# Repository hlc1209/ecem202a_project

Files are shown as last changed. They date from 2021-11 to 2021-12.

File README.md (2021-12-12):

# ECEM202A Project
## BLE-enabled HID based on Edge Inference Accelerated Handwriting Recognition
This is repository template for UCLA ECEM202A / CSM213A projects.

Use the folders as follows:

* doc/ for website content
* software/ for code used in your project
* data/ for data data used in your project

You may add additional folders as necessary

# Website URL
https://hlc1209.github.io/ecem202a_project/

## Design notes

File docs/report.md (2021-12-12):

# Final Report
# Table of Contents
* Abstract
* [Introduction](#1-introduction)
* [Related Work](#2-related-work)
* [Technical Approach](#3-technical-approach)
* [Evaluation and Results](#4-evaluation-and-results)
* [Discussion and Conclusions](#5-discussion-and-conclusions)
* [References](#6-references)

# Abstract

In this project, we build a low-cost, small-size and low-power real-time handwritten character recognition system based on Arduino Nano 33 BLE Sense with a touch screen, which is capable of offering fluent handwriting input experience in real-time and send recognized characters to BLE-enabled terminal equipment as keyboard strokes. Inference of character recognition deep learning model is done on the Arduino Nano 33 BLE Sense to enable the compatibility to any BLE-enabled devices. We achieve a accuracy of 80.6% in fast mode with a latency of 200ms and 95.4% in slow mode. In addition, we designed the PCB and 3D printed case for the device to reduce the use of flying wires and to make the device integrated and portable.

<p align="middle">
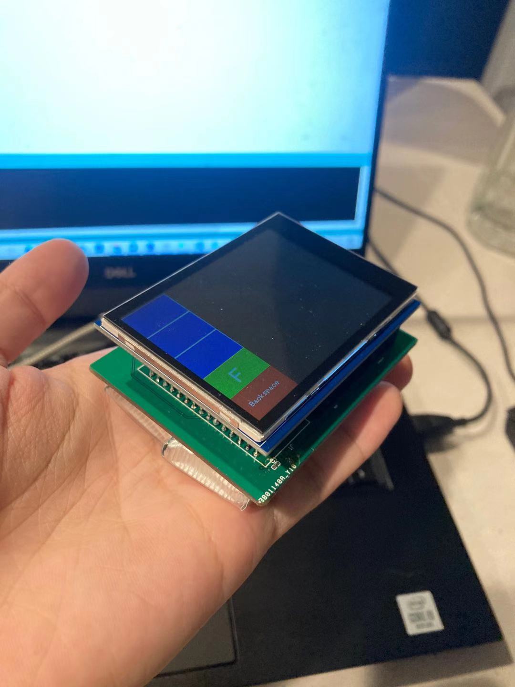
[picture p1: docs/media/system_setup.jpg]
    
</p>

# 1. Introduction

#### 1.1 Motivation & Objective
Designers have long recognized that handwriting with a pen offers more fluidity compared with typing. After the keyboard has been the dominant input device for electronics for years, stylus pen comes into play as another commonly-used input device for electronics. While stylus pen becomes increasingly popular over the years, problems remain in this type of device, which could be turned into sizable market if properly solved. 

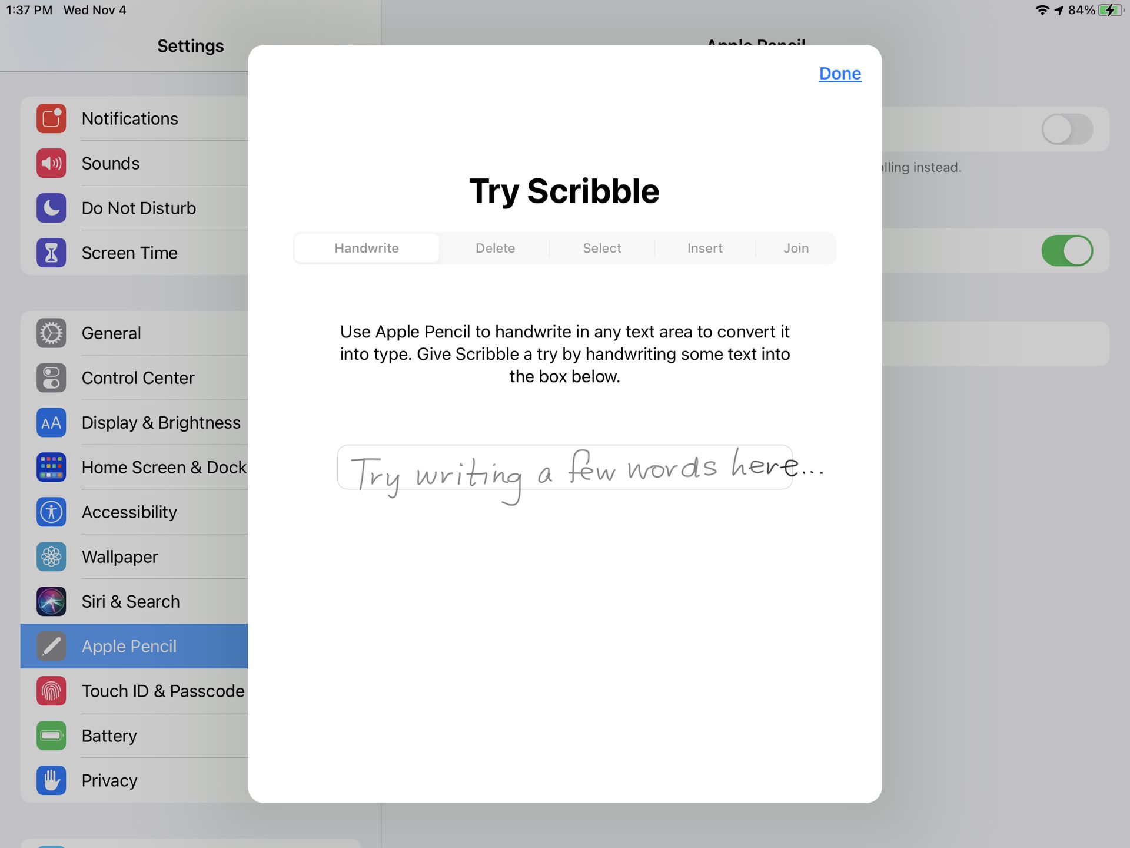
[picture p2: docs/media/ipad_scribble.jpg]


First, the cost of handwritten-enabled devices with a smooth experience is high. Currently, multiple solutions exist for scribble digitization. For example, Microsoft Surface Pro has a built-in Wacom-made digitizer layer and a pen designed for it to achieve such functionality. Apple iPad introduced the scribble feature in iOS 14 with an extremely enhanced seamless handwriting input experience, but it requires the powerful computing power of the A14 chip and a separately sold apple pencil. Other solutions like capacitive and bluetooth stylus have readily lower cost. Still, they can only work with devices with touchscreen enabled and rely on hardware-specific optimized software to deliver a good experience. It is undeniably true that the vast majority of low-end devices offer a very poor handwriting experience.

Secondly, hardware support is relatively stringent. Most of the handwritten solutions for electronics does not generalize well to different devices and mainly focus on the need of high-end electronics. Also, if handwritten characters are used as input, the recognition of handwritten characters becomes the burden on the interfaced device, placing demands on the system's software and hardware performance, increasing the system's complexity and reducing its reliability and real-time performance.

To tackle the aforementioned problems, we propose to develop a low-cost and low-power device with a capacitive touchscreen that is able to offers a fluent handwriting input experience and send commands/keyboard strokes to bluetooth low energy (BLE) enabled devices as an alternative to conventional keyboard input. Such device is essentially a new type of human interface devices (HID) and able to work universally with any BLE enabled devices with minimum change in firmware. Since the handwritten recognition is done on this embedded device, there would be little hardware constraints for the interfaced devices except BLE capability. 

#### 1.2 Novelty & Rationale

Nowadays, handwritten recognition solutions either work on specialized devices or touchscreen enabled high-end electronics, e.g., BMW iDrive infotainment system and Apple iPad. Also, the handwritten recognition algorithm of these devices typical requires the support of powerful processors. We envision a system with a small touch screen built in to collect handwritten inputs and infer the written characters on chip before sending out the commands/keyboard strokes. 

Therefore, high compatibility and fluent input experience on a low-cost, low-power compact device is the main aspect that makes our proposed device stand out from other touchscreen solutions available in the market. 

Moreover, given the flexibility of handwritten input, the device has unlimited possibilities for extended functionality. For example, performing calculations on handwritten numbers and symbols and transmitting the final results to the terminal equipment via BLE.

#### 1.3 Potential Impact

If successfully made, this device could become a new type of human interface device that is compatible to any BLE enable devices not limited to high-end electronics like laptops and tablets. For instance, it could be used to recognize and convert user's writings to keyboard strokes to replace the functionality of a keyboard upon user's desire. Similarly, it could also become an input device of speech-synthesizer for speech impaired people. 

In short, such device brings a new way of electronic interface with high performance, great compatibility and low cost. 

#### 1.4 Challenges

First of all, the experience of handwriting recognition input is critical, i.e., low latency, high accuracy and high efficiency. After we decided to use on-device deep learning inference for handwriting character recognition, it became pivotal to implement fast and accurate model inference while handling GUI drawing, user stroke input and BLE transmission on an ultra-low power device. Secondly, how to achieve fluent handwriting input on ultra-low power devices is to be overcome. We need a deep collaboration of deep learning models and GUI to achieve this. Likewise, data transmission via BLE is very important and needs to be user friendly, low latency and highly reliable. 

#### 1.5 Requirements for Success

To build such a system, the following skill sets and resources are needed.

Skill sets
* Embedded system
* Real-time operating system
* Bluetooth Low Energy (BLE)
* SPI and I2C
* Electronics
* Machine Learning and model compression

Skill sets potentially in need
* PCB design
* Mechanical Design

Hardware
* Arduino Nano 33 BLE Sense
* Adafruit 2.8" TFT Touch Shield v2 (capacitive touch)
* Breadboard

Hardware potentially in need
* Boost converter
* 3d Printer

#### 1.6 Metrics of Success: 

The success of the project will be evaluated through the following metrics. 

1. Accuracy:
   The success rate of recognizing written characters.

2. Response time:
   The time from finishing writing a character to the completion of transmission.

3. Fluentness: 
   The time to write a series of characters.

4. Power consumption:
   The power consumption of the entire system.

5. Size & Weight:
   The size and weight of the overall system.

# 2. Related Work

In 2018, Fernández et. al developed a real-time handwritten letter recognition system based on Raspberry Pi 3 using ConvNets which is able to achieve an accuracy of 93.4% and an average response time of 21.9 ms. This is the best performance of all similar systems that run the machine learning model offline considering accuracy, response, power consumption, and size. 

However, limitations remain on this system. First, the machine learning used in this system is still too large for the microcontroller. Also the model could be further compressed with proper pruning, quantization, and other model compression techniques. Second, by replacing the Raspberry Pi 3 with a low-power microcontroller (i.e., the Arduino Nano 33 BLE Sense in our case), the power consumption and size of the system can be further reduced. Finally and most importantly, this article only demonstrates the feasibility of individual character recognition using deep learning networks in embedded systems, and does not illustrate the performance of handwriting recognition in real-world applications when coupled with peripherals, such as touch screen and BLE-enabled terminals. 

In 2019, Google Research uses recurrent neural network to enable seamless handwriting input on Android devices. Unlike traditional hand-designed heuristics to cut the handwritten input into single characters, Google build an RNN model that operates on the whole input. They convert a series of handwritten inputs into a sequence of Bessel curves that are fed into the RNN to get the actual written characters.

Nevertheless, this powerful approach relies on strong chips on Android devices and even requires specially designed chips like Google Tensor with TPU cores to deliver smooth interactions, which is unacceptable in our project.

# 3. Technical Approach

## 3.1 Operation Logic
The User Interface of the device is shown in figure below. The black square area allows user to write/draw characters with fingers or stylus pen. The left panel is divided into 5 parts. The first 3 buttons on the top are the selection buttons used in slow mode. The 4th button from the top is used to switch between fast and slow mode. The red backspace button is used to delete text or clear screen without sending the keyboard stroke in slow mode. 

<p align="middle">
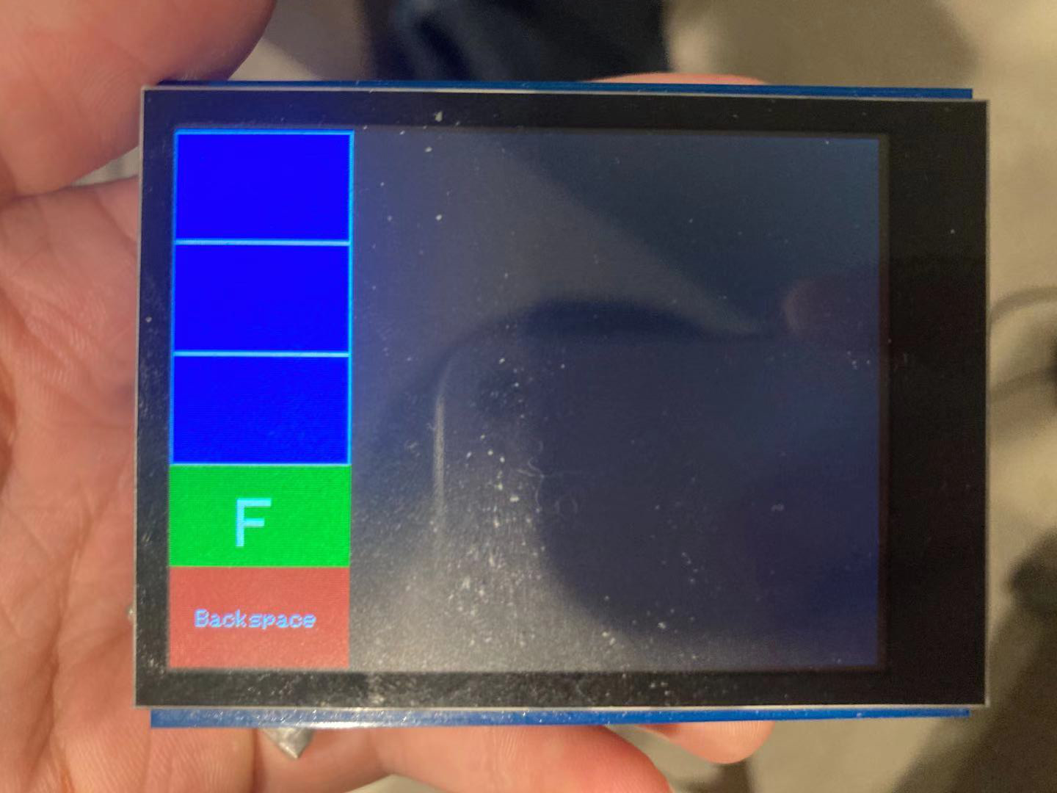
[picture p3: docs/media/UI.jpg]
    
</p>

#### Fast Mode 
In fast mode, after the user is done writing one character, the character with the highest score from inference is sent out through Bluetooth Low Energy immediately. Such setup allows maximum input speed.

#### Slow Mode
In slow mode, the written character will not be sent out instantly after the inference is done. Rather, the characters with the top 3 scores from the inference will be printed in the blue panel, allowing users to confirm and select the correct character to send out as keyboard stroke. If none of the inferred character matches user's input, the user can simply tap the 'backspace' button to clear the screen and rewrite the character. With such design, the input speed is slower in exchange for more robust inference.

<p align="middle">
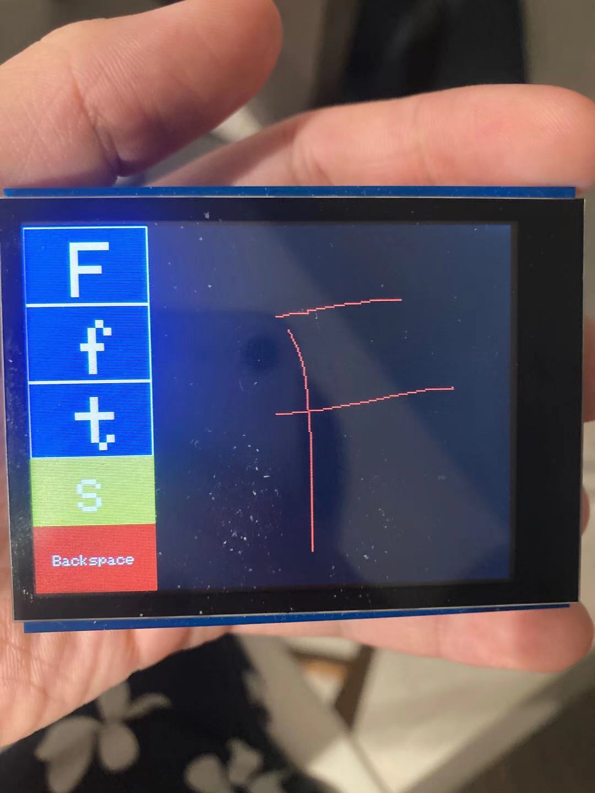
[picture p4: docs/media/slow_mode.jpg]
    
</p>

## 3.2 Bluetooth Low Energy
In contrast to Bluetooth classic, BLE is designed for significantly low power consumption, which is suitable for our application. Keyboard service is a reserved service in BLE, which eliminates the burden of writing custom service to send keyboard strokes. The inferred character will be written as BLE characteristic to BLE keyboard service to achieve the wireless keyboard functionality.

## 3.3 Image Resizing
The size of black canvas that records user's drawing is 240-by-240, which is 57.6k input parameters in total. Indeed, high-resolution image typically enables better prediction accuracy through neural network. However, considering the computing resource provided by Arduino Nano 33 BLE Sense, it is necessary to reduce the model size to deploy the model to Arduino Nano 33 BLE Sense with real-time inference. Also, pixels are represented by truth values.

For fast resizing, we use box sampling to sum the pixel values in a box and skip the rest of the values once the sum is greater than 0. During testing, we realized the recognition accuracy is affected by the thickness of strokes. Therefore, we artificially increase the stroke thickness by 3 times when performing downsizing. A comparison of writing on screen and the resized image is shown in figure below.

<p align="middle">
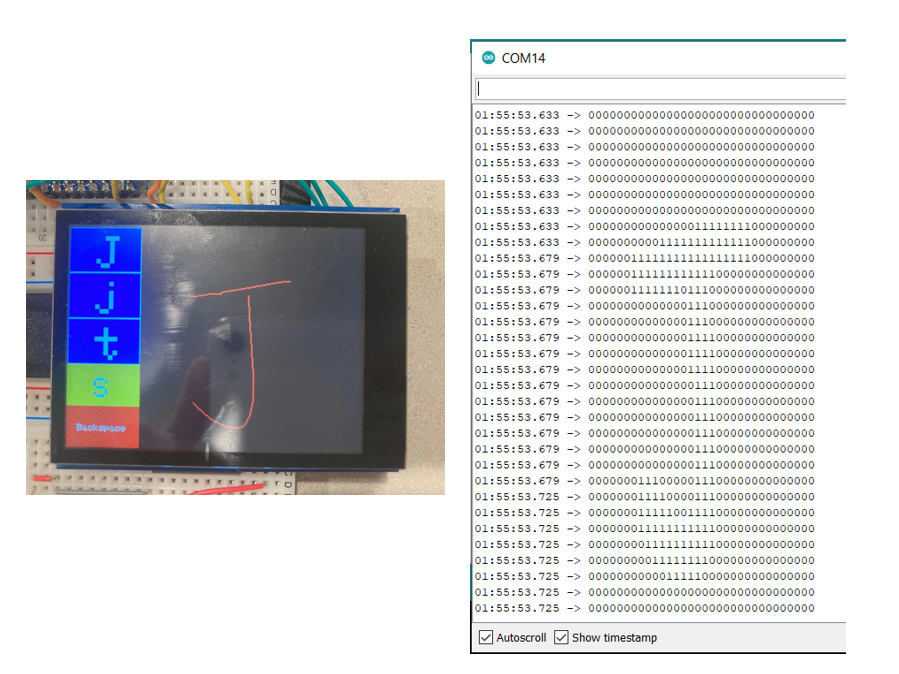
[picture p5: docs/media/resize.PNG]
    
</p>

## 3.4 Printed Circuit Board Design
The system is first built on breadboard, shown in the figure below. After the basic functionality is verified, we ported the design to a 2-layer PCB to eliminate the jumper wires and improve mobility. We use easyEDA to PCB drawing for the ease of PCB ordering. The PCB drawing and finished PCB are shown in the figures below, respectively.
<p align="middle">
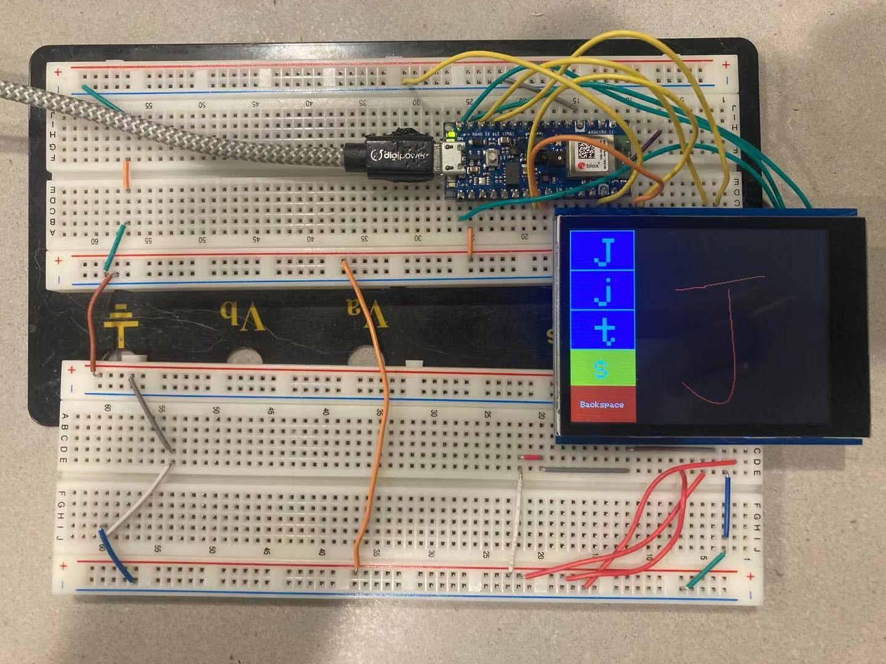
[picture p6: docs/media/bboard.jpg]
    
</p>

<p align="middle">
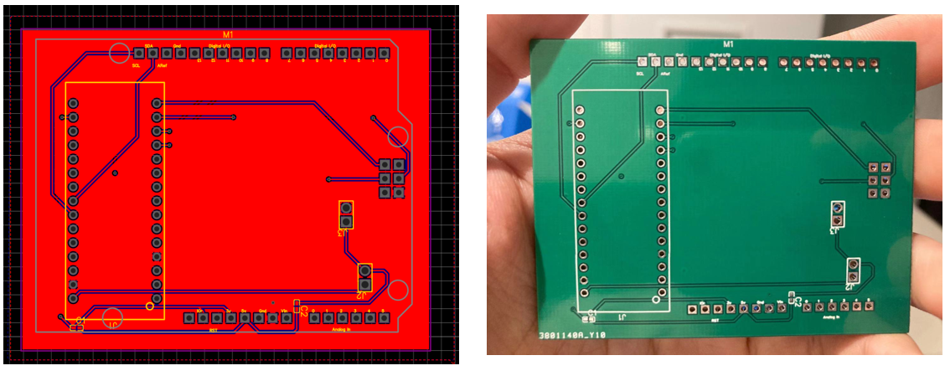
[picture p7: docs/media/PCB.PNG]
    
</p>

In our PCB design, 2 3.7V LiPo batteries are used as power source. 2 3.7V LiPo batteries are placed in series to supply 7.4V voltage to Arduino Nano 33 BLE Sense. Our chosen touchscreen Adafruit ILI9341 has a built-in LDO and accepts input voltage from 2.7V to 5.5V. Since Arduino Nano 33 BLE Sense has a 3.3V pin, we decided to add 2 capacitor footprints where 1 footprint connects 3.3V to the input of touchscreen and the other one connects 3.7V (voltage of one of the battery) to test which supply voltage is more stable. 

## 3.5 Firmware
The workflow of the firmware can be represented in the diagram below. There are two threads operating in parallel and 1 semaphore to help with the timing of two threads. One thread controls the operation of BLE, mainly the write characteristic command and the other thread controls the touchscreen as well as the inference of user's input. BLE thread releases the semaphore when it is done writing characteristic and touchscreen thread releases the semaphore when inference is done. 

<p align="middle">
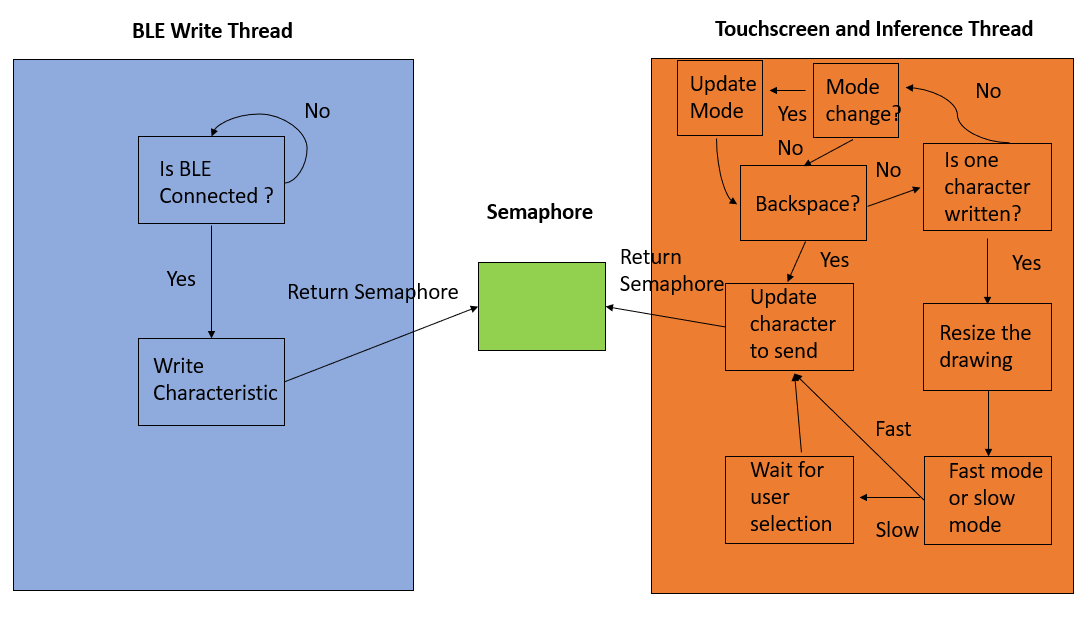
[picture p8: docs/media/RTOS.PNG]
    
</p>

Debouncing is crucial for touchscreen applications. We allow 30ms between each touch on screen. When the user is drawing consecutive lines, we record the coordinate of start and end point and draw a straight line between these two points as the approximate trajectory. The straight line is estimated using Bresenham's algorithm. Doing so also alleviate the issue of insufficient SPI clock speed since the SPI clock speed is locked at 1 Mhz on Arduino Nano 33 BLE Sense. This issue has not been resolved. Reports of this issue can be found [here](https://forum.arduino.cc/t/nano-33-ble-spi-speed-not-changing/656881) and [here](https://issueexplorer.com/issue/arduino/ArduinoCore-mbed/270).

Many characters are usually written in more than one consecutive stroke such as '4', 'B', and 'F'. To allow those characters to be captured, the firmware would wait for the next stroke for 150 ms before resizing and inference.

## 3.6 3D-printed Model for packaging
3D models shown in the figure below are drawn in SolidWorks for packaging purpose. However, due to the significant delay of shipping, we have not received the 3D models yet. Thus, we are not able to verify the mechanical design.

<p align="middle">
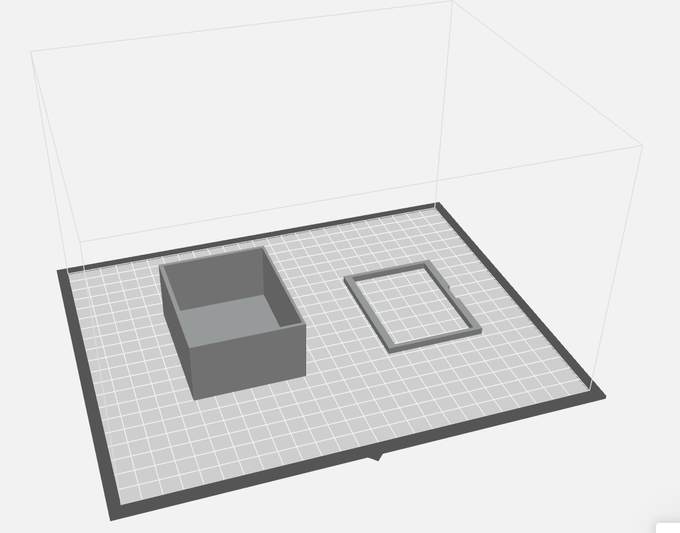
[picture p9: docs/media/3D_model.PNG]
    
</p>

## 3.7 Character recognition using Deep Learning

For the handwritten character recognition, the traditional method is to use OCR algorithms. However, for the Arduino Nano 33 BLE Sense we are using, most OCR algorithms require well over 1MB of flash space, and demand more computational capacity than a microcontroller can provide for real-time processing.

To develop real-time character recognition algorithms that can be used on microcontrollers, we use deep learning to build and train a model that can achieve about 85% accuracy on 0-9 and a-z handwritten characters. To make real-time processing possible on the Arduino Nano 33, we utilize a variety of  optimization skills to build a tiny convolutional neural network, which has only 50k parameters in total, and the inference time on the device is ~100ms.

#### Dataset & Data Preprocessing

The dataset we used is Extended MNIST (EMNIST), which contains 814,255 characters in 62 classes. Compared to the MNIST dataset, it's about 12 times larger and includes a-z characters. Due to its huge scale, we didn't use other datasets to train the model.

We observed that there are four things that will cause a severe performance degradation in the real world related to the dataset: 

1. Handwritten characters have an arbitrary angle with respect to the touch screen. However, the dataset we used does not consider this situation.
2. Handwritten characters have an arbitrary size relative to the touch screen, but the training characters from the dataset all have the same size.
3. Handwritten characters have an arbitrary position relative to the touch screen, but the training characters in the dataset are all located in the center.
4. The strokes we obtain from the touch screen are a series of sampled points, which we then convert into a 1-bit character image for the deep learning model's input. But, the characters images in the dataset are all 8-bit grayscale. 

To address the issues listed above, as well as to improve the performance of the model in the real world, we make use of data augmentation. The preprocessing and augmentation sequence we used are:

1. Rescale the images to the float datatype of 0.0~1.0.
2. Randomly rotate the image within an angle from -15 degree to 15 degree. This is to solve the first problem mentioned above.
3. Randomly resize the original 28\*28 image to a new square image of size from 16\*16 to 34\*34. Therefore the training characters will have different size. This is to solve the second problem mentioned above.
4. Crop the resized image into a square image of size 32\*32 with random cropping positions. Thus, the training characters will be positioned at different position. This is to solve the third problem mentioned above.
5. Binarize image to 1-bit image. The threshold we use is 0.3. This will solve the final problem listed above.

The figures below are some examples of the original dataset images before pre-processing and augmentation.

<p align="middle">
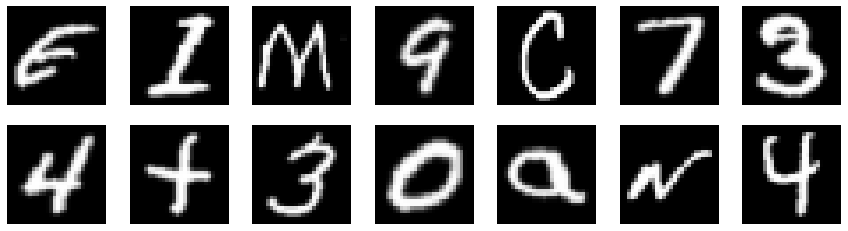
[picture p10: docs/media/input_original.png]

</p>

The figures below are some examples of the training images after pre-processing and augmentation. Each figure is generated using one original image .

<p align="middle">
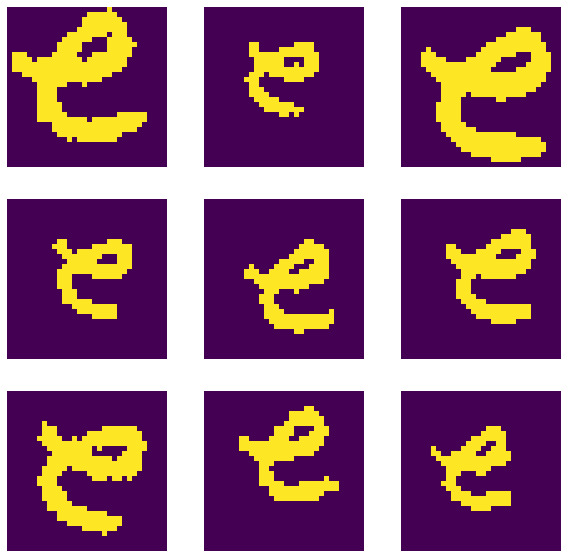
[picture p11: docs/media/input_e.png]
   
   &nbsp;&nbsp;&nbsp;&nbsp;
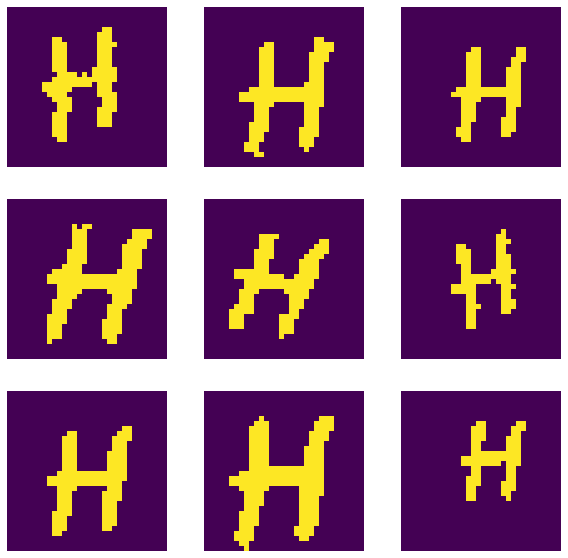
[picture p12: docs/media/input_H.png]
   
   &nbsp;&nbsp;&nbsp;&nbsp;
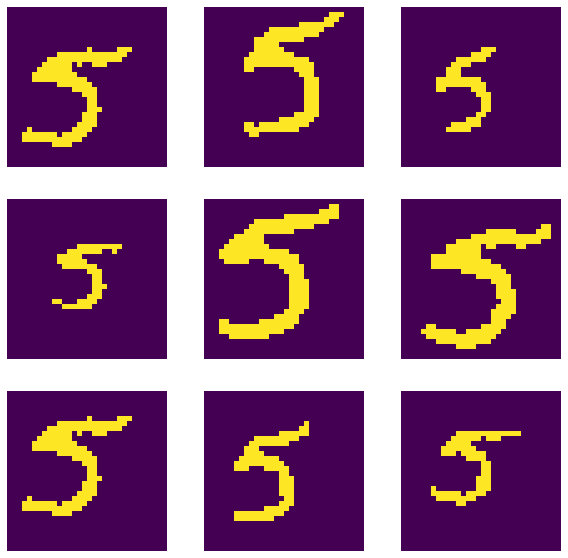
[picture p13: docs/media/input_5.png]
   
</p>

#### Design Model Architecture
Due to the limitation of Arduino Nano 33 BLE, there are strict limitations on model architecture. The following requirements should be met for the success of this project:

1. Considering the target overall latency after the user finished writing a character is 200ms, the inference time should be equal or less than 150ms.
2. The layers available in Tensorflow Lite Micro are limited. Some common layers are not available, such as BatchNormalization layer.
3. The Arduino Nano 33 BLE has only 256 KB of SRAM. in addition, a large portion of the memory is needed to run the touch screen, generate input images, and send strokes using the BLE. So the available RAM space is limited.
4. The Arduino Nano 33 BLE has 1 MB of flash. Although this is still a small number compared to common neural networks, we didn't have any issue with flash space, since to meed the inference time requirement, the model is small enough.

The following is the model architecture we used: (right click to open a bigger view)

<p align="middle">
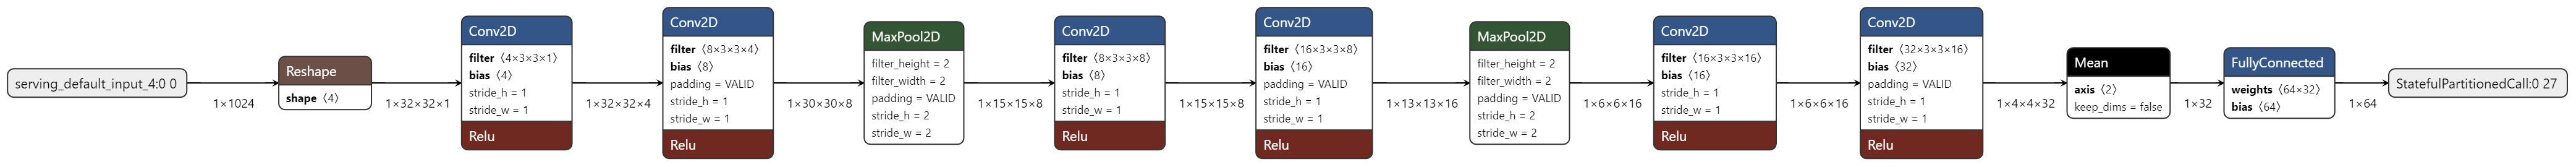
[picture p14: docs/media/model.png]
    
</p>

To achieve the best performance in a tiny model, I use multiple convolutional layer at the same level, and instead of using a big window size (e.g. 5 or 7) for the convolution layer, I set the window size of all convolutional layers to 3. It is a valuable conclusion from VGG that multiple 3x3 convolutional layers have better performance than one large convolutional layer,while also saving a lot of parameters. 

Another idea from recent research is that instead of using a flatten layer and 2 fully connected layers at the top of the network, I use one GlobalAveragePooling layer and an output FC layer. This setting has the best performance and can save a lot of parameters. I also tried FC+FC, GlobalMaxPooling+FC and GlobalMaxPooling alone, but GlobalAveragePooling+FC is the best.

We have tried many activation functions, such as ReLU, PReLU, ELU and other variants. However, PReLU, ELU and other variations cannot beat ReLU in our project.

The final model architecture has 11,160 parameters in total. The accuracy on the training set is 81.59% and on the test set is 83.64%.

#### Implementation & Optimization

We use Tensorflow to implement and train the model and then use Tensorflow Lite Micro to quantize and convert the model to C header file.

There are many techniques to optimize the model for edge computing devices, such as quantization, quantization aware training, pruning, and so on. 

We have tried quantization aware training but did not observe any performance improvement. Similarly, we did not use pruning because the current version of Tensorflow Lite Micro will not benefit from pruning, i.e., the latency will not decrease.

For the quantization part, we quantize not only the weights and biases but also the input and output of the model. Both are quantized to 8-bit.

When quantizing and converting the model, we face a bug in Tensorflow Lite Micro, which is that the reshape layer cannot be quantized correctly. More specifically, the output of the reshape layer will be 32-bit integer datatype, which is not supported by Arduino Tensorflow Lite Micro. A illustration of the bug is shown below.

<p align="middle">
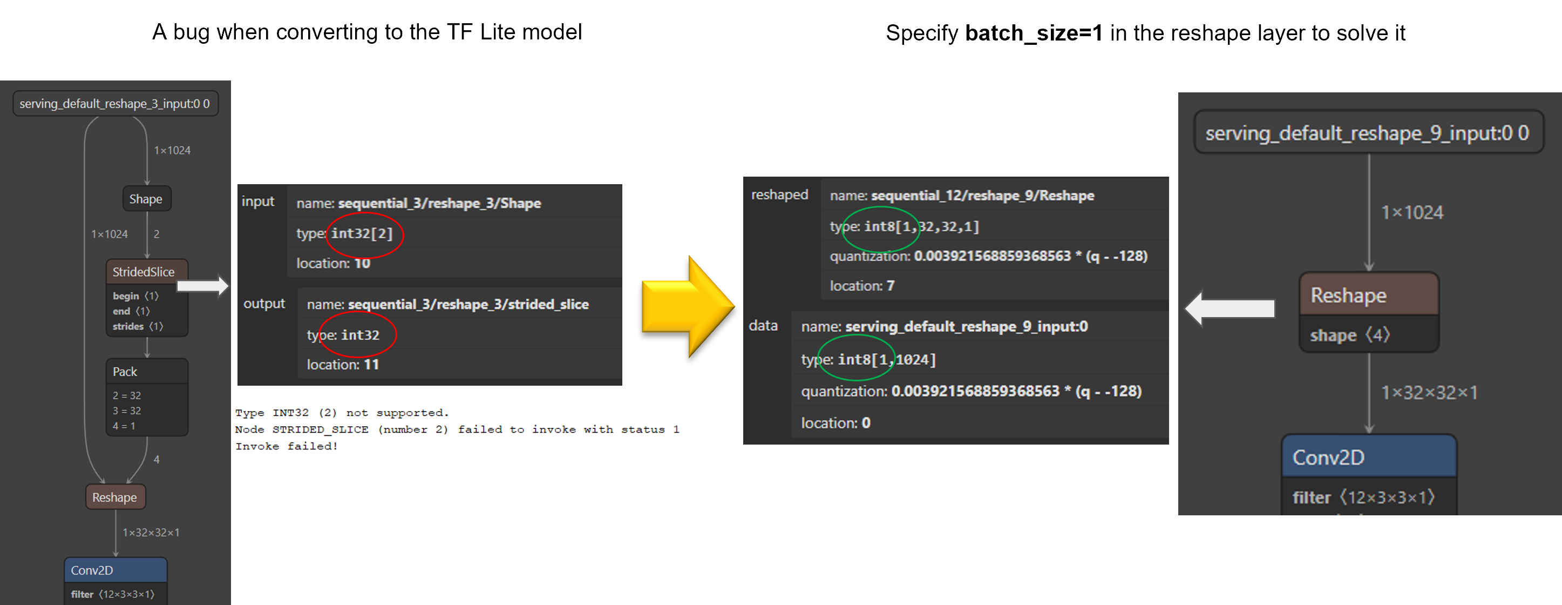
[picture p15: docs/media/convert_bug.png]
    
</p>

The bug is reported in this [github page](https://github.com/tensorflow/tensorflow/issues/45256) and this [github page](https://github.com/tensorflow/tensorflow/issues/50286), but we haven't see any official solution until the latest Tensorflow release.

We spent a lot of time on this and found a perfect solution, as the image shown above. In the training stage, we use normal setting for the reshape layer, i.e., batch_size=32 or 64. In the converting stage, we create a new model with the same architecture, but set the batch_size of the reshaping layer to 1, and transfer the weights and biases to the new model. Finally, we convert the new model to C header file.

This perfectly solves the bug, without any loss of performance during training on the GPU and inference on the board.

# 4. Evaluation and Results
## 4.1 Evaluation on the Test Set

We evaluate the model on two datasets: EMNIST and MNIST.

For the MNIST dataset, we achieved a test accuracy of 95.38%. Considering the model is trained on the EMNIST dataset, we can say that the model has good generalization capability. The confusion matrix is shown below.
<p align="middle">
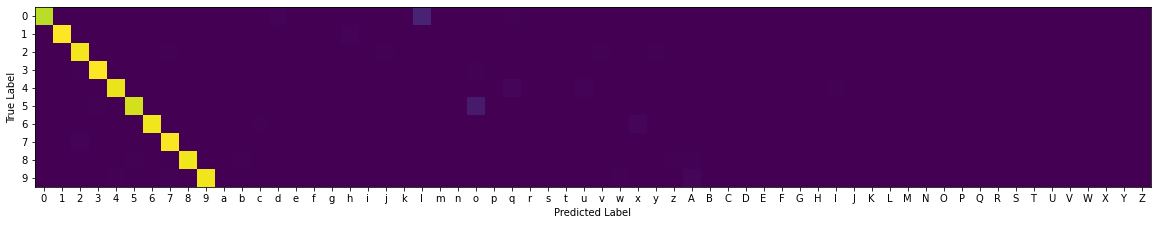
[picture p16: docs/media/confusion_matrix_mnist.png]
    
</p>

For the EMNIST dataset, we achieved a test accuracy of 83.71%. Considering the 83.64% evaluation accuracy during training, quantization does not bring performance degradation. The confusion matrix is shown below.
<p align="middle">
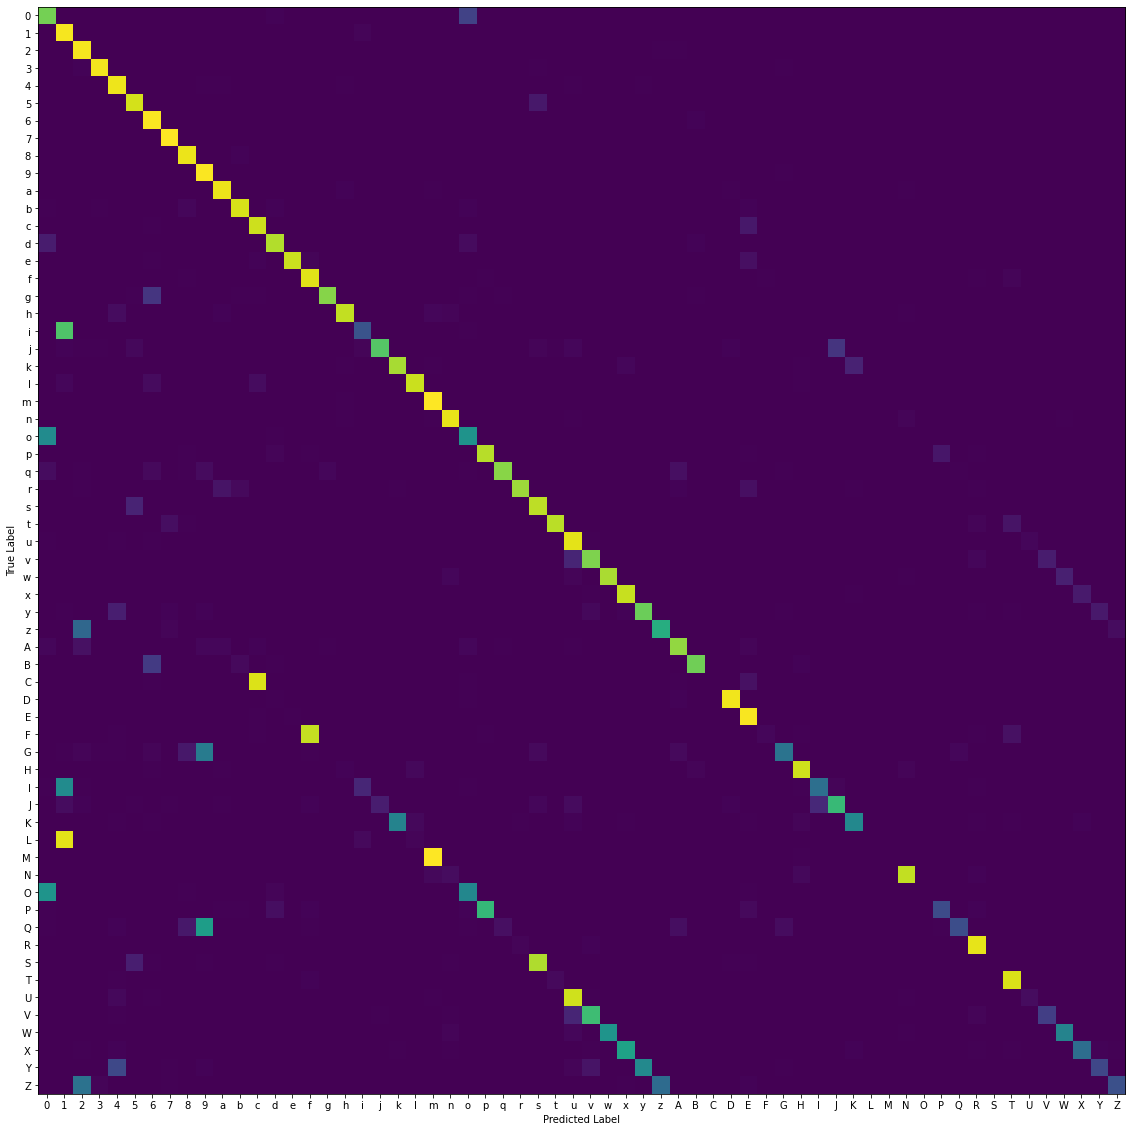
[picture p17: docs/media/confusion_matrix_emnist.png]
    
</p>

A detailed analysis of the confusion matrix is shown in the [Discussion](#51-error-analysis) section.

## 4.2 Real world evaluation
After the system is migrate from breadboard to PCB, 2 demonstrations are made for fast mode and slow mode. Refer to the links below.

#### Demo Video for Fast Mode
<p align="middle">
<iframe width="80%" height="300"
src="https://www.youtube.com/embed/TnqZWla2pq8" 
frameborder="0" 
allow="accelerometer; encrypted-media; picture-in-picture" 
allowfullscreen></iframe>
</p>

* [Video File for Fast Mode](https://github.com/hlc1209/ecem202a_project/raw/main/docs/media/fast_demo.mp4)

#### Demo Video for Slow Mode
<p align="middle">
<iframe width="80%" height="300"
src="https://www.youtube.com/embed/La2jUmT9tKs" 
frameborder="0" 
allow="accelerometer; encrypted-media; picture-in-picture" 
allowfullscreen></iframe>
</p>

* [Video File for Slow Mode](https://github.com/hlc1209/ecem202a_project/raw/main/docs/media/slow_demo.mp4)

For evaluations, the system is tested with 2 3.7V LiPo battery as the power source shown in the figure below. Then, the recognition latency and recognition accuracy are tested. The recognition accuracy is tested under fast mode and slow mode separately. In the test for slow mode, we count the trial as success if the written character shows up as 1 of the 3 selections on the left panel. In the test for fast mode, when calculating accuracy, only if the highest scoring character in the output matches the input is considered successful. In testing for accuracy, we handwrite each character (0 to 9, a to z, and A to Z) for 5 times and calculate the average accuracy over all characters. The accuracy for fast mode is 80.6% and the accuracy for slow mode is 95.4%. 

Refer to the following excel files for detailed testing results:

* [Test Results for Fast Mode](https://github.com/hlc1209/ecem202a_project/raw/main/data/testing_fast_mode.xlsx)

* [Test Results for Slow Mode](https://github.com/hlc1209/ecem202a_project/raw/main/data/testing_slow_mode.xlsx)

## 4.3 Latency Analysis
In latency evaluation, we record the time spent on resizing the image until the inferred character gets sent out through BLE in fast mode. The latency is printed in the serial monitor and we calculate the average latency from 50 trials. The recorded data can be found [here](https://github.com/hlc1209/ecem202a_project/raw/main/data/testing_latency.xlsx). The average latency over 50 trials is 208.1 ms. We've reached the preset goal from proposal.

<p align="middle">
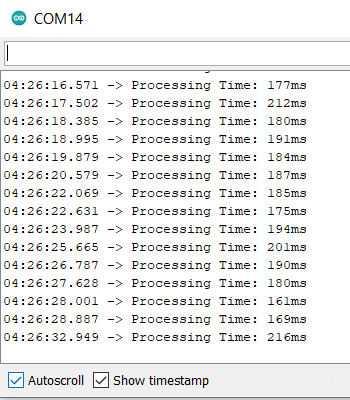
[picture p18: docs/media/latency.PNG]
    
</p>

# 5. Discussion and Conclusions

In this project, we implement a low-cost and low-power real-time handwritten character recognition system using Arduino Nano 33 BLE Sense. A optimized convolutional neural network are designed and trained to recognize handwritten characters and achieved 95.38% accuracy on MNIST dataset and 83.71% accuracy on EMNIST dataset. The inference time on the board after optimization is 114ms. To build a integrated and portable handwriting recognition system, we designed a 3D printed case and PCB with 2 3.7V Lipo battery as power supply. The whole system is tested in real world application and achieved 80.6% accuracy in fast mode with a 200ms latency and 95.4% in slow mode. Unfortunately, due to delay in shipping, we did not received the 3D-printed model to furnish the product. Thus, we leave this for future work to improve the mechanical design. 

## 5.1 Error Analysis 
Due to the limitation of the performance of the Arduino Nano 33 BLE, as well as the size of the available touchscreen, we choose to allow only one character on the screen at a time, rather than writing a whole sentence. 

This compromise is not only for the convenience of the user, but also for the efficiency of the system. However, it also brings harmful effects to the recognition accuracy. As we can see in the confusion matrix shown below, there are some obvious errors.

<p align="middle">
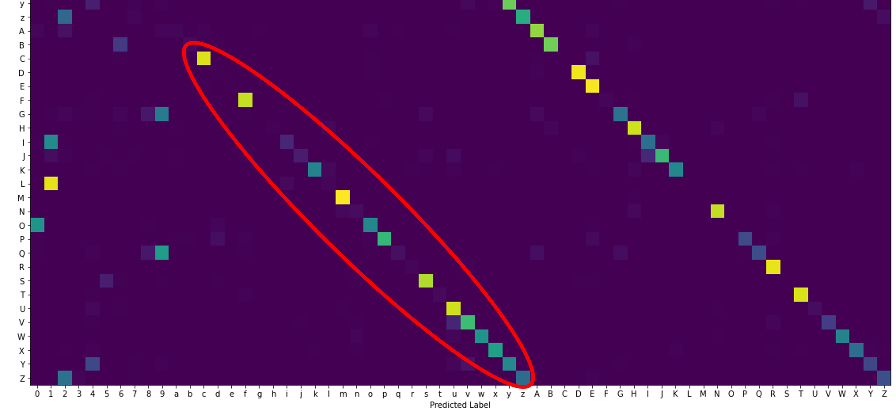
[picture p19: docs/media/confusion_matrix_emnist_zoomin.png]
    
</p>

The errors in the red circle are due to the fact that it is almost impossible to distinguish the upper and lower case letters when only giving a single character without context. For example, the pair 'x' and 'X', the pair 'o' and 'O', the pair 'z' and 'Z', and the pair 's' and 'S'. 

A simple method to deal with this problem is to always output the lower case letters, since the situation that the upper case letters are written is very rare.

Other errors on the left of the circle are due to the similarity between numbers and letters. For example, the pair '0' and 'O', the pair '1' and 'l', the pair '2' and 'Z', and the pair '3' and 'S'. 

It is almost impossible to deal with these errors as long as we only allow one character each time on the screen. Allowing more characters on the screen, or deploying a time-series deep learning model, is not a good idea for this microcontroller.

Fortunately, we developed the slow mode that allows the user to choose top 3 characters. The accuracy of the system is improved to 95.4% in the slow mode and in most cases, the user can get the correct character without having to write it again.

## 5.2 Future Work
First, the clock speed of SPI is locked at 1 Mhz on Arduino Nano 33 BLE because of imperfection in Arduino's mbed core, which somewhat degrades the performance of our system. With a faster SPI clock speed, we can achieve much smoothier visual effect and drawing experience. Currently, due to the limit of SPI clock speed, Bresenham's algorithm is used to estimated the trajectory. Therefore, zigzaging drawings may occur when drawing curves. The figure below is a common example. Also, when drawing large amount of pixels (for example, startup, print top-3-score characters), it is obvious that pixels are drawn lines by lines. The limitation of SPI speed of nRF52840 is 32 Mhz. We have rooms to optimize the user experience in terms of the screen effect. 

<p align="middle">
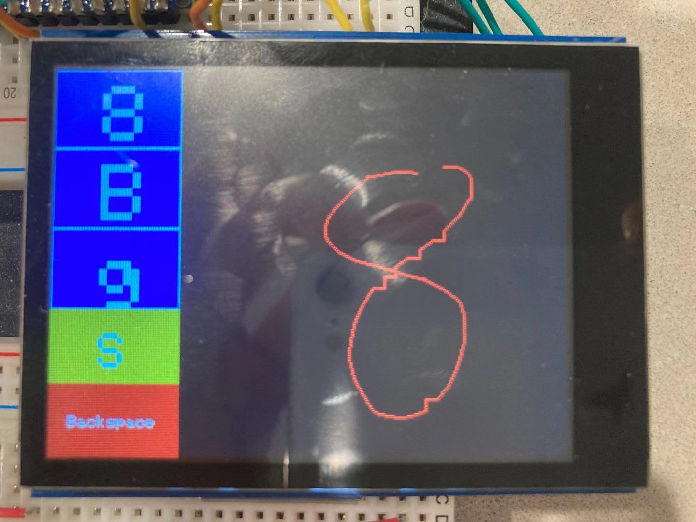
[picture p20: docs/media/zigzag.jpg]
    
</p>

Second, electrical and mechanical designs need to be optimized. For electrical designs, we consider using a boost converter to provide 5V as the input voltage to the touchscreen. Currently, 3.7V which is the voltage provided by one of the battery is directly connected to the input of the touchscreen. We notice that the touchscreen dims occasionally due to the lower voltage supply. We also need to design switch for power on and off the device, as well as charging mechanism of the battery without disassembling the system. For mechanical design, we consider optimizing the layout of the PCB for the convenience for future development. As shown in the figure below, the USB port for development is blocked when the touchscreen is in place. Also, the 3D models for packaging need to be modified to incorporate the power switch and charging port.

<p align="middle">
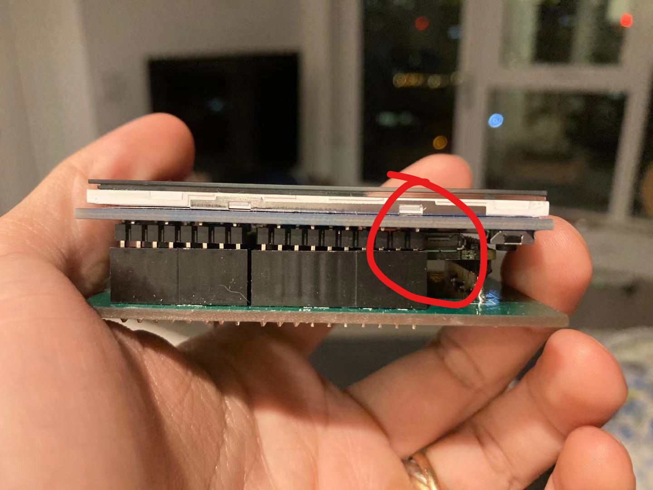
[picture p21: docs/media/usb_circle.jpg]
    
</p>

Third, more evaluation of accuracy need to be done for different user, especially the ones that have no prior knowledge of the system. As developers are more familiar with the training dataset, it is very likely that we are biased to write characters that are more likely to be captured by the model, thus, overestimate the capability of the system. Ideally, more trials with different users need to be performed in the future to validate the performance.

# 6. References

D. Núñez Fernández and S. Hosseini, "Real-Time Handwritten Letters Recognition on an Embedded Computer Using ConvNets," 2018 IEEE Sciences and Humanities International Research Conference (SHIRCON), 2018, pp. 1-4, doi: 10.1109/SHIRCON.2018.8592981.

Saldanha, Luca Bochi and Christophe Bobda. “An embedded system for handwritten digit recognition.” J. Syst. Archit. 61 (2015): 693-699.

Carbune, Victor, et al. "Fast multi-language LSTM-based online handwriting recognition." International Journal on Document Analysis and Recognition (IJDAR) 23.2 (2020): 89-102.

Feuz, Sandro, and Pedro Gonnet. “RNN-Based Handwriting Recognition in Gboard.” Google AI Blog, 7 Mar. 2019, http://ai.googleblog.com/2019/03/rnn-based-handwriting-recognition-in.html.

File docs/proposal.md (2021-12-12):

# Proposal
# 1. Motivation & Objective

Designers have long recognized that handwriting with a pen offers more fluidity compared with typing. After the keyboard has been the dominant input device for electronics for years, stylus pen comes into play as another commonly-used input device for electronics. While stylus pen becomes increasingly popular over the years, problems remain in this type of device, which could be turned into sizable market if properly solved. 



First, the cost of handwritten-enabled devices with a smooth experience is high. Currently, multiple solutions exist for scribble digitization. For example, Microsoft Surface Pro has a built-in Wacom-made digitizer layer and a pen designed for it to achieve such functionality. Apple iPad introduced the scribble feature in iOS 14 with an extremely enhanced seamless handwriting input experience, but it requires the powerful computing power of the A14 chip and a separately sold apple pencil. Other solutions like capacitive and bluetooth stylus have readily lower cost. Still, they can only work with devices with touchscreen enabled and rely on hardware-specific optimized software to deliver a good experience. It is undeniably true that the vast majority of low-end devices offer a very poor handwriting experience.

Secondly, hardware support is relatively stringent. Most of the handwritten solutions for electronics does not generalize well to different devices and mainly focus on the need of high-end electronics. Also, if handwritten characters are used as input, the recognition of handwritten characters becomes the burden on the interfaced device, placing demands on the system's software and hardware performance, increasing the system's complexity and reducing its reliability and real-time performance.

To tackle the aforementioned problems, we propose to develop a low-cost and low-power device with a capacitive touchscreen that is able to offers a fluent handwriting input experience and send commands/keyboard strokes to bluetooth low energy (BLE) enabled devices as an alternative to conventional keyboard input. Such device is essentially a new type of human interface devices (HID) and able to work universally with any BLE enabled devices with minimum change in firmware. Since the handwritten recognition is done on this embedded device, there would be little hardware constraints for the interfaced devices except BLE capability. 

# 2. State of the Art & Its Limitations

In 2018, Fernández et. al developed a real-time handwritten letter recognition system based on Raspberry Pi 3 using ConvNets which is able to achieve an accuracy of 93.4% and an average response time of 21.9 ms. This is the best performance of all similar systems that run the machine learning model offline considering accuracy, response, power consumption, and size. 

However, limitations remain on this system. First, the machine learning used in this system is still too large for the microcontroller. Also the model could be further compressed with proper pruning, quantization, and other model compression techniques. Second, by replacing the Raspberry Pi 3 with a low-power microcontroller (i.e., the Arduino Nano 33 BLE Sense in our case), the power consumption and size of the system can be further reduced. Finally and most importantly, this article only demonstrates the feasibility of individual character recognition using deep learning networks in embedded systems, and does not illustrate the performance of handwriting recognition in real-world applications when coupled with peripherals, such as touch screen and BLE-enabled terminals. 

In 2019, Google Research uses recurrent neural network to enable seamless handwriting input on Android devices. Unlike traditional hand-designed heuristics to cut the handwritten input into single characters, Google build an RNN model that operates on the whole input. They convert a series of handwritten inputs into a sequence of Bessel curves that are fed into the RNN to get the actual written characters.

Nevertheless, this powerful approach relies on strong chips on Android devices and even requires specially designed chips like Google Tensor with TPU cores to deliver smooth interactions, which is unacceptable in our project.

# 3. Novelty & Rationale

Nowadays, handwritten recognition solutions either work on specialized devices or touchscreen enabled high-end electronics, e.g., BMW iDrive infotainment system and Apple iPad. Also, the handwritten recognition algorithm of these devices typical requires the support of powerful processors. We envision a system with a small touch screen built in to collect handwritten inputs and infer the written characters on chip before sending out the commands/keyboard strokes. 

Therefore, high compatibility and fluent input experience on a low-cost, low-power compact device is the main aspect that makes our proposed device stand out from other touchscreen solutions available in the market. 

Moreover, given the flexibility of handwritten input, the device has unlimited possibilities for extended functionality. For example, performing calculations on handwritten numbers and symbols and transmitting the final results to the terminal equipment via BLE.

# 4. Potential Impact

If successfully made, this device could become a new type of human interface device that is compatible to any BLE enable devices not limited to high-end electronics like laptops and tablets. For instance, it could be used to recognize and convert user's writings to keyboard strokes to replace the functionality of a keyboard upon user's desire. Similarly, it could also become an input device of speech-synthesizer for speech impaired people. 

In short, such device brings a new way of electronic interface with high performance, great compatibility and low cost. 

# 5. Challenges

First of all, the experience of handwriting recognition input is critical, i.e., low latency, high accuracy and high efficiency. After we decided to use on-device deep learning inference for handwriting character recognition, it became pivotal to implement fast and accurate model inference while handling GUI drawing, user stroke input and BLE transmission on an ultra-low power device. Secondly, how to achieve fluent handwriting input on ultra-low power devices is to be overcome. We need a deep collaboration of deep learning models and GUI to achieve this. Likewise, data transmission via BLE is very important and needs to be user friendly, low latency and highly reliable. 

# 6. Requirement for Success

To build such a system, the following skill sets and resources are needed.

#### Skill sets
* Embedded system
* Real-time operating system
* Bluetooth Low Energy (BLE)
* SPI and I2C
* Electronics
* Machine Learning and model compression

#### Skill sets potentially in need
* PCB design
* Mechanical Design

#### Hardware
* Arduino Nano 33 BLE Sense
* Adafruit 2.8" TFT Touch Shield v2 (capacitive touch)
* Breadboard

#### Hardware potentially in need
* Boost converter
* 3d Printer

# 7. Metrics of Success

The success of the project will be evaluated through the following metrics. 

1. Accuracy:
   The success rate of recognizing written characters.

2. Response time:
   The time from finishing writing a character to the completion of transmission.

3. Fluentness: 
   The time to write a series of characters.

4. Power consumption:
   The power consumption of the entire system.

5. Size & Weight:
   The size and weight of the overall system.

# 8. Execution Plan

The project can be partitioned into 5 mandatory tasks and 2 optional tasks:

1. Development of the embedded system.
   Interface the touchscreen to obtain handwritten characters properly. Develop BLE connection between Arduino Nano 33 BLE Sense and laptop. 

2. Machine learning model development:
   Develop and compress machine learning model to meet the accuracy and response time criteria with respect to the hardware constraint.

3. System Integration:
   Fully integrate the machine learning model with the touch screen and BLE to achieve basic system features. 

4. Model Optimization:
   Optimize the machine learning model for fluent handwritten input, improved accuracy, and reduced model runtime.

5. System optimization:
   Reduce system latency and optimize the GUI to improve user interaction experience.

6. Extended Functionality (Optional):
   Implement some interesting functionalities, e.g., direct calculation and custom shortcuts.

7. System packaging (Optional):
   Migrate the system from breadboard to a perfboard/PCB with proper power system if time allowed. Design a 3D-printed package to minimize the size of the entire system. 

Yu Nong will be mainly responsible for task 1, 3, 5, 6, 7 and Hanlong Chen will be mainly responsible for task 2, 3, 4, 6, 7.

The proposed timeline is the following.

#### Week 1-2 (Oct. 4-17) 

* Research for project ideas with focus on human interface device (HID)
* Form a team of 2 considering the scope and difficulty of the project.
  
#### Week 3 (Oct. 18-24) 

* Create project website on Github and finish the section of abstract.
* Discuss project idea and validate the feasibility.
* Place order for necessary components.
* Research into the user Manual and tutorial of the purchased components.

#### Week 4 (Oct. 25-31)

* Finalize detailed project ideas and create timeline for the project. 
* Analyze applications and review literatures that are similar to this project.
* Start wiring and testing of the touchscreen.
* Start collecting datasets for DL model training and building the model architecture using PC.

#### Week 5 (Nov. 1-7)

* Finish wiring and interfacing the touchscreen with Arduino Nano 33 BLE Sense.
* Train the DL model using GPU and keep adjusting the architecture to obtain better performance with smaller model sizes.

#### Week 6 (Nov. 8-14)

* Finish BLE connection between Arduino Nano 33 BLE Sense and PC with HID keystroke input.
* Attempt to run trained models on Arduino Nano 33 BLE Sense and profiling the performance to adjust the architecture.

#### Week 7-8 (Nov. 15-21)

* Finish pruning, digitization, and model compression on ML model.
* Implement the compressed ML model in Arduino Nano 33 BLE Sense. 
* Achieve real-time DL model inference on Arduino Nano 33 BLE Sense with decent recognition accuracy.
* Achieve a basic graphical user interface, including handwriting input area and candidate words area.
* Resolve issues on timing and ensure the system meets the minimum requirement of real-time response.
* Prepare a demo video and report as a progress update.

#### Week 9-10 (Nov. 22- Dec. 5)

* Tune the and further compress the ML model to improve the performance on both accuracy and timing.
* Add more functions to the GUI to enable more interesting interactions.
* Debug issues found through testing.
* Consider to make a 3D-printed case to package the system.

#### Week 11 (Dec. 6-11)
* Evaluate the performance of the furnished system and compose the final report.
* Update the project website with detail testing results, source code, and thorough documentation.
* Prepare Zoom presentation. 

# 9. Related Work

## 9.a. Papers

An article closely related to our project is "Real-Time Handwritten Letters Recognition on an Embedded Computer Using ConvNets" by D. Núñez Fernández and S. Hosseini. 

While this article demonstrates the basic feasibility of our project, the plan for our project goes beyond the level demonstrated in this article.

In this article, the described method is implemented using the Raspberry Pi 3 which comes with 1GB RAM and 1.2 GHz main clock speed, we are aiming to reproduce a system with similar performance using Arduino Nano 33 BLE Sense which has only 256KB RAM and 64 MHz main clock speed. In this paper, authors were able to achieve an accuracy of 93.4% with a response time of 21.9 ms. Such high performance in both accuracy and response time is at the cost of a more expensive and power-consuming device. However, we notice that the machine learning models implemented in Raspberry Pi 3 are not optimized using any of the emerging model compression techniques such as pruning and quantization. Therefore, it is feasible to achieve similar performance on a less power device with a much more compressed model with reasonable cost in accuracy and response time. 

The proposed method in the article performance only one task, which simply outputs the model results of a single static handwritten character, and does not illustrate the performance of handwriting recognition in real-world applications where efficiency, usability, and accuracy are extremely important. In our anticipated system, we propose to extend the functionality of the system to do deep learning-based fluent handwriting input in conjunction with capturing user's stroke input through touch screen and interacting with external device via BLE. In this context, two tasks exist simultaneously. One is the recognition of handwritten characters and the other is the BLE service as the interface between devices. Due to the sporadic nature of the first task, the scheduling scheme of these two events needs to be carefully evaluated and addressed.

## 9.b. Datasets

[A-Z Handwritten Alphabets in .csv format](https://www.kaggle.com/sachinpatel21/az-handwritten-alphabets-in-csv-format)

[MNIST handwritten digit database](http://yann.lecun.com/exdb/mnist/)

[Extended MNIST](https://www.nist.gov/itl/products-and-services/emnist-dataset)

[Handwritten Digits and Operators](https://www.kaggle.com/michelheusser/handwritten-digits-and-operators)

[Handwritten math symbols dataset](https://www.kaggle.com/xainano/handwrittenmathsymbols)

## 9.c. Software

Arduino IDE, VS Code, Matlab, Python, Tensorflow Lite

# 10. References

D. Núñez Fernández and S. Hosseini, "Real-Time Handwritten Letters Recognition on an Embedded Computer Using ConvNets," 2018 IEEE Sciences and Humanities International Research Conference (SHIRCON), 2018, pp. 1-4, doi: 10.1109/SHIRCON.2018.8592981.

Saldanha, Luca Bochi and Christophe Bobda. “An embedded system for handwritten digit recognition.” J. Syst. Archit. 61 (2015): 693-699.

Carbune, Victor, et al. "Fast multi-language LSTM-based online handwriting recognition." International Journal on Document Analysis and Recognition (IJDAR) 23.2 (2020): 89-102.

Feuz, Sandro, and Pedro Gonnet. “RNN-Based Handwriting Recognition in Gboard.” Google AI Blog, 7 Mar. 2019, http://ai.googleblog.com/2019/03/rnn-based-handwriting-recognition-in.html.

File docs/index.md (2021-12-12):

# Main Page
# BLE-enabled HID based on Edge Inference Accelerated Handwriting Recognition
# Abstract

In this project, we build a low-cost, small-size and low-power real-time handwritten character recognition system based on Arduino Nano 33 BLE Sense with a touch screen, which is capable of offering fluent handwriting input experience in real-time and send recognized characters to BLE-enabled terminal equipment as keyboard strokes. Inference of character recognition deep learning model is done on the Arduino Nano 33 BLE Sense to enable the compatibility to any BLE-enabled devices. We achieve a accuracy of 80.6% in fast mode with a latency of 200ms and 95.4% in slow mode. In addition, we designed the PCB and 3D printed case for the device to reduce the use of flying wires and to make the device integrated and portable.

<p align="middle">
    
</p>

# Team

* Name of team member \#1 Yu Nong
* Name of team member \#2 Hanlong Chen

# Required Submissions

* [Proposal](proposal)
* [Midterm Checkpoint Presentation Slides](https://github.com/hlc1209/ecem202a_project/raw/main/docs/M202A%20Midterm%20Presentation.pptx)
* [Final Presentation Slides](https://github.com/hlc1209/ecem202a_project/raw/main/docs/M202A%20Final%20Presentation.pptx)
* [Final Report](report)

# Highlights

#### Demo Video for Fast Mode
<p align="middle">
<iframe width="80%" height="300"
src="https://www.youtube.com/embed/TnqZWla2pq8" 
frameborder="0" 
allow="accelerometer; encrypted-media; picture-in-picture" 
allowfullscreen></iframe>
</p>

* [Video File for Fast Mode](https://github.com/hlc1209/ecem202a_project/raw/main/docs/media/fast_demo.mp4)

#### Demo Video for Slow Mode
<p align="middle">
<iframe width="80%" height="300"
src="https://www.youtube.com/embed/La2jUmT9tKs" 
frameborder="0" 
allow="accelerometer; encrypted-media; picture-in-picture" 
allowfullscreen></iframe>
</p>

* [Video File for Slow Mode](https://github.com/hlc1209/ecem202a_project/raw/main/docs/media/slow_demo.mp4)

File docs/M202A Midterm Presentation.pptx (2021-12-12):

## Midterm Checkpoint Presentation

Group members:
Yu Nong
Hanlong Chen

## Overall Project Goals and Specific Aims

Goals: Build a low-power and real-time handwritten character recognition system based on Arduino Nano 33 BLE Sense with a touch screen.
Anticipated recognition accuracy: 85%. Anticipated recognition delay: 150 ms.
Deliverables:

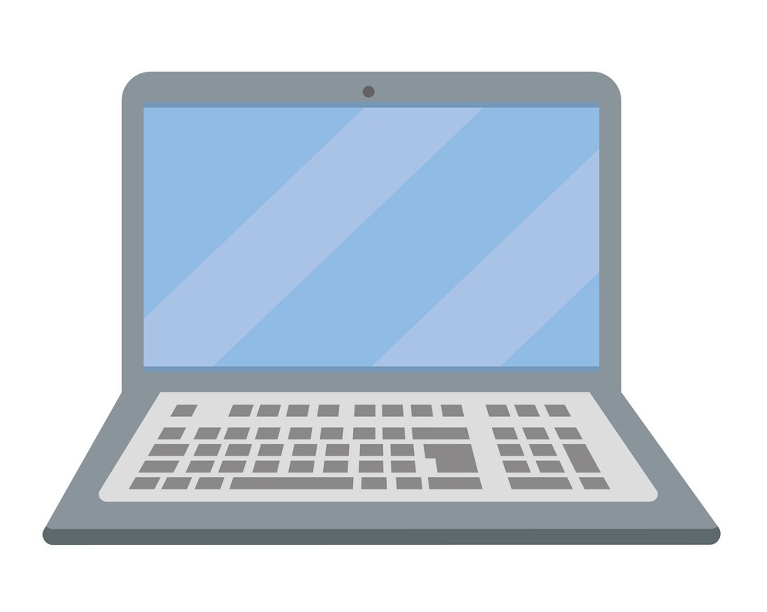
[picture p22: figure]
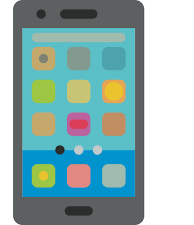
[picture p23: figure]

BLE

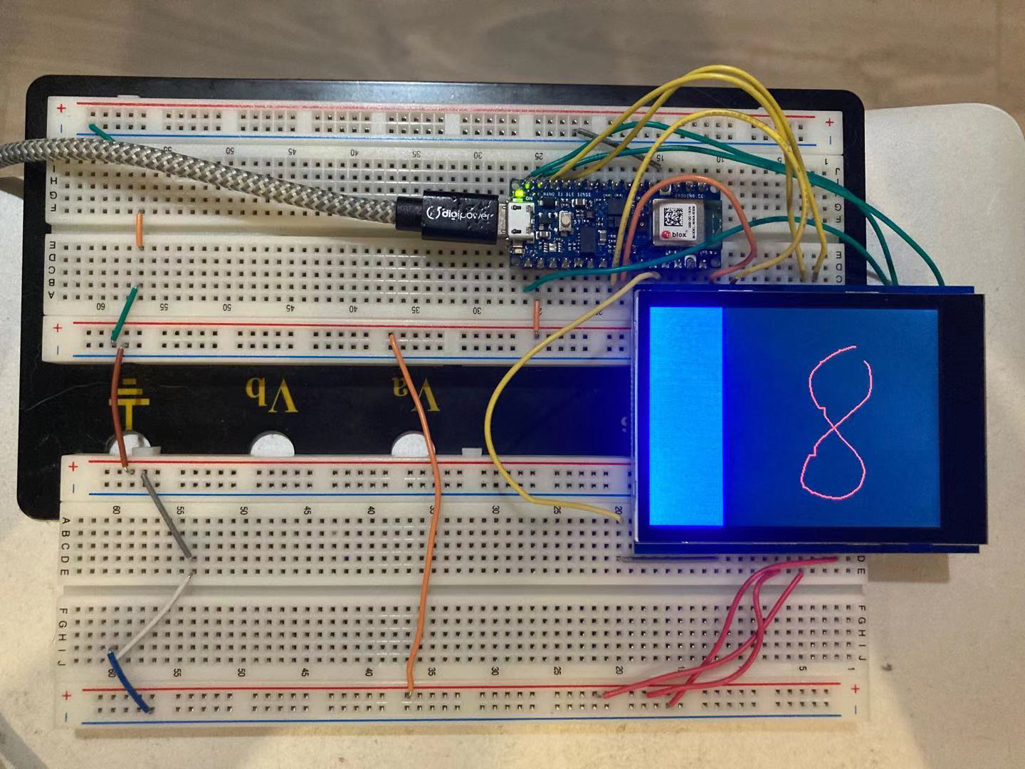
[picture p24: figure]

## Technical Approach - Deep Learning


1. Design and train a network from scratch.
2. Use pre-trained networks and apply transfer learning.

| Million parameters | Accuracy | Inference time on Arduino
Our network | 0.03-0.1 | ~98% | 30-100ms
MobileNet v1 | 0.47 | ~91% | 650ms


Input: 32*32 grayscale image for our network
96*96 grayscale image for MobileNet
Output: 10 classes
Optimizer: Adam
Loss: Cross entropy


## Current Status



Specify batch_size=1 in the reshape layer



## Next Step

- Continue to tune and compress the model and incorporate recognition of English letter and other characters
- Improve the user interface. For example, adding settings that can be adjusted on the touchscreen.
- Optimize the integrated system to achieve seamless handwriting input
- (Optional) Migrate the system from breadboard to PCB.
- (Optional) Design a 3D-printed case for packaging.


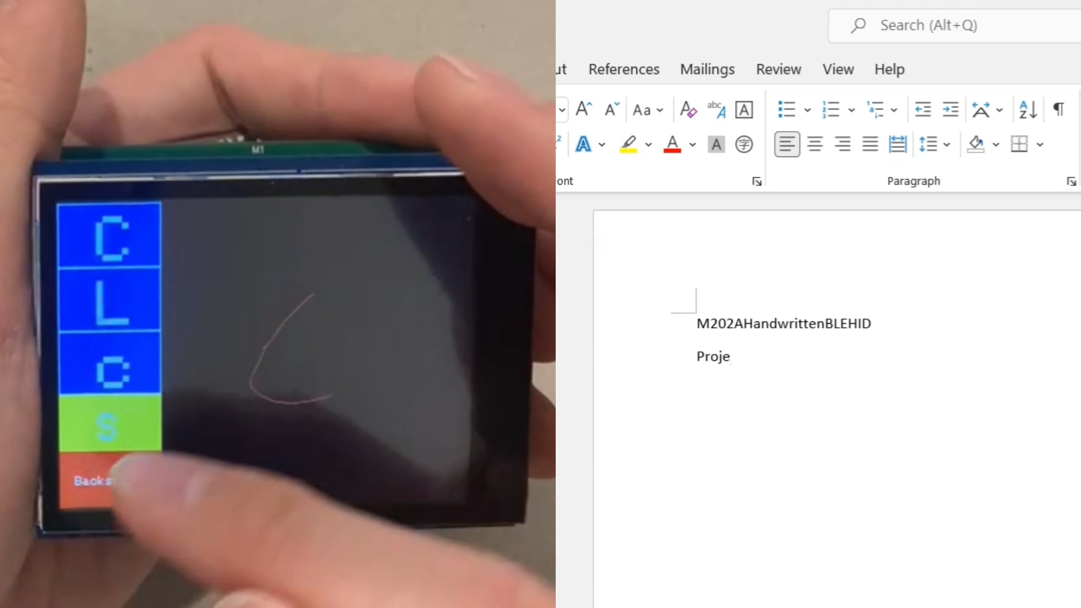
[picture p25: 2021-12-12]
docs/media/demo_screenshot.jpg

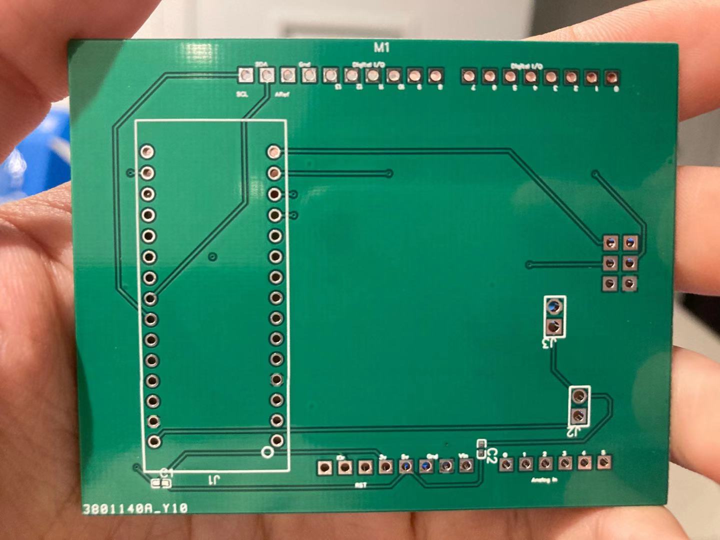
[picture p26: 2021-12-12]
docs/media/pcb.jpg

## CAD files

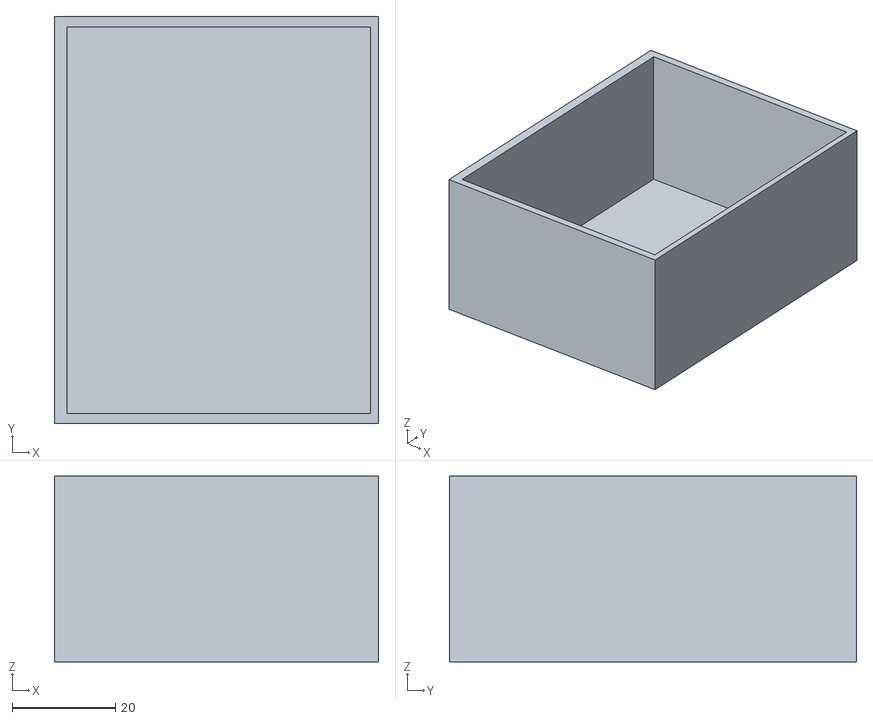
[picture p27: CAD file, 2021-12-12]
data/Part1.STL
62.9 x 78.9 x 36.0

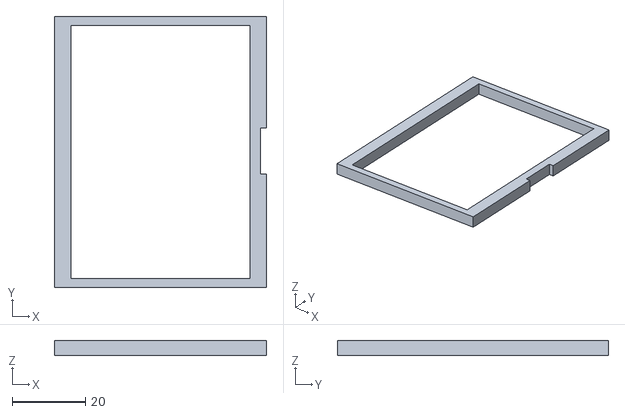
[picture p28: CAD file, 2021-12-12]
data/Part2.STL
57.9 x 73.9 x 4.00

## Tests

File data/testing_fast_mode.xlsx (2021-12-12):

Character | Correct Count | Total Count | Accuracy | Tota Accuracy
0 | 5 | 5 | 100.00% | 80.6451612903%
1 | 5 | 5 | 100.00%
2 | 5 | 5 | 100.00%
3 | 5 | 5 | 100.00%
4 | 5 | 5 | 100.00%
5 | 4 | 5 | 80.00%
6 | 5 | 5 | 100.00%
7 | 5 | 5 | 100.00%
8 | 5 | 5 | 100.00%
9 | 5 | 5 | 100.00%
a | 4 | 5 | 80.00%
b | 4 | 5 | 80.00%
c | 0 | 5 | 0.00%
d | 5 | 5 | 100.00%
e | 5 | 5 | 100.00%
f | 0 | 5 | 0.00%
g | 3 | 5 | 60.00%
h | 5 | 5 | 100.00%
i | 4 | 5 | 80.00%
j | 5 | 5 | 100.00%
k | 4 | 5 | 80.00%
l | 5 | 5 | 100.00%
m | 0 | 5 | 0.00%
n | 4 | 5 | 80.00%
o | 0 | 5 | 0.00%
p | 0 | 5 | 0.00%
q | 4 | 5 | 80.00%
r | 3 | 5 | 60.00%
s | 0 | 5 | 0.00%
t | 5 | 5 | 100.00%
u | 0 | 5 | 0.00%
v | 3 | 5 | 60.00%
w | 5 | 5 | 100.00%
x | 4 | 5 | 80.00%
y | 1 | 5 | 20.00%
z | 3 | 5 | 60.00%
A | 5 | 5 | 100.00%
B | 5 | 5 | 100.00%
C | 5 | 5 | 100.00%
D | 5 | 5 | 100.00%
E | 5 | 5 | 100.00%
F | 4 | 5 | 80.00%
G | 4 | 5 | 80.00%
H | 5 | 5 | 100.00%
I | 5 | 5 | 100.00%
J | 5 | 5 | 100.00%
K | 5 | 5 | 100.00%
L | 5 | 5 | 100.00%
M | 5 | 5 | 100.00%
N | 5 | 5 | 100.00%
O | 2 | 5 | 40.00%
P | 5 | 5 | 100.00%
Q | 5 | 5 | 100.00%
R | 5 | 5 | 100.00%
S | 5 | 5 | 100.00%
T | 5 | 5 | 100.00%
U | 5 | 5 | 100.00%
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

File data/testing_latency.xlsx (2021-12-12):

 | latency | Average Latency
04:23:05.880 -> Processing Time: 165ms | 165 | 208.1
04:23:08.065 -> Processing Time: 213ms | 213
04:23:09.652 -> Processing Time: 199ms | 199
04:23:11.146 -> Processing Time: 216ms | 216
04:23:13.478 -> Processing Time: 190ms | 190
04:23:14.556 -> Processing Time: 217ms | 217
04:23:15.396 -> Processing Time: 201ms | 201
04:23:16.614 -> Processing Time: 235ms | 235
04:23:17.589 -> Processing Time: 218ms | 218
04:23:19.693 -> Processing Time: 199ms | 199
04:23:22.400 -> Processing Time: 213ms | 213
04:23:23.518 -> Processing Time: 240ms | 240
04:23:24.360 -> Processing Time: 191ms | 191
04:23:25.014 -> Processing Time: 178ms | 178
04:23:25.524 -> Processing Time: 180ms | 180
04:23:26.875 -> Processing Time: 220ms | 220
04:23:29.578 -> Processing Time: 227ms | 227
04:23:30.515 -> Processing Time: 230ms | 230
04:23:31.635 -> Processing Time: 183ms | 183
04:23:32.850 -> Processing Time: 206ms | 206
04:23:34.201 -> Processing Time: 226ms | 226
04:23:34.906 -> Processing Time: 192ms | 192
04:23:36.352 -> Processing Time: 229ms | 229
04:23:37.373 -> Processing Time: 197ms | 197
04:23:39.054 -> Processing Time: 225ms | 225
04:23:40.219 -> Processing Time: 220ms | 220
04:23:41.573 -> Processing Time: 251ms | 251
04:23:43.251 -> Processing Time: 201ms | 201
04:23:44.277 -> Processing Time: 217ms | 217
04:23:45.302 -> Processing Time: 208ms | 208
04:23:46.240 -> Processing Time: 160ms | 160
04:23:46.986 -> Processing Time: 147ms | 147
04:23:49.785 -> Processing Time: 195ms | 195
04:23:51.141 -> Processing Time: 201ms | 201
04:23:52.776 -> Processing Time: 207ms | 207
04:24:19.914 -> Processing Time: 197ms | 197
04:24:21.547 -> Processing Time: 196ms | 196
04:24:23.741 -> Processing Time: 206ms | 206
04:24:27.002 -> Processing Time: 222ms | 222
04:24:28.080 -> Processing Time: 169ms | 169
04:24:30.651 -> Processing Time: 238ms | 238
04:24:31.865 -> Processing Time: 224ms | 224
04:24:33.403 -> Processing Time: 193ms | 193
04:24:34.615 -> Processing Time: 233ms | 233
04:24:35.830 -> Processing Time: 202ms | 202
04:24:40.163 -> Processing Time: 265ms | 265
04:24:41.192 -> Processing Time: 200ms | 200
04:24:43.377 -> Processing Time: 245ms | 245
04:25:40.517 -> Processing Time: 153ms | 253
04:25:44.253 -> Processing Time: 165ms | 165

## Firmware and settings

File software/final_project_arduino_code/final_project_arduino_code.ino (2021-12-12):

#include <mbed.h>
#include <mbed_wait_api.h>
#include <rtos.h>
#include <Adafruit_GFX.h>    // Core graphics library
#include <SPI.h>       // this is needed for display
#include <Adafruit_ILI9341.h>
#include <Wire.h>      // this is needed for FT6206
#include <Adafruit_FT6206.h>

#include "Nano33BleHID.h"
#include "signal_utils.h"

#include <TensorFlowLite.h>
#include <tensorflow/lite/micro/all_ops_resolver.h>
#include <tensorflow/lite/micro/micro_error_reporter.h>
#include <tensorflow/lite/micro/micro_interpreter.h>
#include <tensorflow/lite/schema/schema_generated.h>
#include <tensorflow/lite/version.h>

#include "model.h"

using namespace rtos;
using namespace mbed;
using namespace std;

// global variables used for TensorFlow Lite (Micro)
tflite::MicroErrorReporter tflErrorReporter;

// pull in all the TFLM ops, you can remove this line and
// only pull in the TFLM ops you need, if would like to reduce
// the compiled size of the sketch.
tflite::AllOpsResolver tflOpsResolver;
//static tflite::MicroMutableOpResolver<4> micro_op_resolver;

const tflite::Model* tflModel = nullptr;
tflite::MicroInterpreter* tflInterpreter = nullptr;
TfLiteTensor* tflInputTensor = nullptr;
TfLiteTensor* tflOutputTensor = nullptr;

// Create a static memory buffer for TFLM, the size may need to
// be adjusted based on the model you are using
char recChar = 'a';
char recChar1 = 'a';
char recChar2 = 'a';
char recChar3 = 'a';
int charIndex1 = 0;
int charIndex2 = 0;
int charIndex3 = 0;
bool flag = false;
constexpr int Widths = 32;
constexpr int tensorArenaSize = 14600;
//#define tensorArenaSize 3000
static uint8_t tensorArena[tensorArenaSize];

// array to map character index to a name
char CHARACTERS[] = {
  '0',
  '1',
  '2',
  '3',
  '4',
  '5',
  '6',
  '7',
  '8',
  '9',
  'A',
  'B',
  'C',
  'D',
  'E',
  'F',
  'G',
  'H',
  'I',
  'J',
  'K',
  'L',
  'M',
  'N',
  'O',
  'P',
  'Q',
  'R',
  'S',
  'T',
  'U',
  'V',
  'W',
  'X',
  'Y',
  'Z',
  'a',
  'b',
  'c',
  'd',
  'e',
  'f',
  'g',
  'h',
  'i',
  'j',
  'k',
  'l',
  'm',
  'n',
  'o',
  'p',
  'q',
  'r',
  's',
  't',
  'u',
  'v',
  'w',
  'x',
  'y',
  'z',
};

#define NUM_CHARACTERS (sizeof(CHARACTERS) / sizeof(CHARACTERS[0]))

bool sendFlag = false;
uint8_t mode = 0; // fast mode 0, slow mode 1
uint8_t thumbwidth = 32;

int8_t oriImage[240][240] = {0};
int8_t downscaledImage[32][32] = {0};

// The FT6206 uses hardware I2C (SCL/SDA)
Adafruit_FT6206 ctp = Adafruit_FT6206();

// The display also uses hardware SPI, plus #9 & #10
#define TFT_CS 10
#define TFT_DC 9
Adafruit_ILI9341 tft = Adafruit_ILI9341(TFT_CS, TFT_DC);

// Size of the color selection boxes and the paintbrush size
#define BOXSIZE 40

Semaphore sem(1);
Thread t1;
Thread t2;

Nano33BleKeyboard bleKb("Shining Keyboard");

void func1(){
  int16_t x_old = 0;
  int16_t y_old = 0;
  int old_time, now;
  old_time = millis();
  bool writtenFlag = false;

  // get the TFL representation of the model byte array
  tflModel = tflite::GetModel(model);
  if (tflModel->version() != TFLITE_SCHEMA_VERSION) {
    Serial.println("Model schema mismatch!");
    while (1);
  }

  Serial.println("Initialized Successful 2");

  // Create an interpreter to run the model
  tflInterpreter = new tflite::MicroInterpreter(tflModel, tflOpsResolver, tensorArena, tensorArenaSize, &tflErrorReporter);

  Serial.println("Initialized Successful 2.5");
  // Allocate memory for the model's input and output tensors
  tflInterpreter->AllocateTensors();

  Serial.println("Initialized Successful 2.7");

  // Get pointers for the model's input and output tensors
  tflInputTensor = tflInterpreter->input(0);
  tflOutputTensor = tflInterpreter->output(0);

  Serial.println("Initialized Successful 3");
  
  while(1){
    
  sem.acquire();
  // Retrieve a point  
  TS_Point p = ctp.getPoint();
  if (p.z == 0 and writtenFlag){
     now = millis();
     if (now - old_time > 150){

      writtenFlag = false;

      for (int i = 1; i < 31; i++){
        for (int j = 1; j < 31; j++){
          for (int p = 0; p < 8; p++){
            for (int q = 0; q < 8; q++){
              if (oriImage[(i-1)*8+p][(j-1)*8+q] == 1){
                downscaledImage[i-1][j-1] = 1;
                downscaledImage[i-1][j] = 1;
                downscaledImage[i-1][j+1] = 1;
                downscaledImage[i][j-1] = 1;
                downscaledImage[i][j] = 1;
                downscaledImage[i][j+1] = 1;
                downscaledImage[i+1][j-1] = 1;
                downscaledImage[i+1][j] = 1;
                downscaledImage[i+1][j+1] = 1;
                p = p + 8;
                q = q + 8;
              }
            }
          }
        }
      }

// Inference
      for (int y = 0; y < Widths; y++) {  
        for (int x = 0; x < Widths; x++) {
          if (downscaledImage[y][x] == 1){
            tflInputTensor->data.int8[y * Widths + x] = 127;
          }
          else{
          tflInputTensor->data.int8[y * Widths + x] = -128;}
        }
      }

      
      
      TfLiteStatus invokeStatus = tflInterpreter->Invoke();

      int8_t score1 = -128;
      int8_t score2 = -128;
      int8_t score3 = -128;
      for (int i = 0; i < NUM_CHARACTERS; i++) {
        int8_t curr_category_score = tflOutputTensor->data.uint8[i];
        if (curr_category_score > score1){
          score1 = curr_category_score;
          charIndex1 = i;
        }
        else if (curr_category_score > score2){
          score2 = curr_category_score;
          charIndex2 = i;
        }
        else if (curr_category_score > score3){
          charIndex3 = i;
          score3 = curr_category_score;
        }
      }
      recChar1 = CHARACTERS[charIndex1];
      recChar2 = CHARACTERS[charIndex2];
      recChar3 = CHARACTERS[charIndex3];

      if (mode == 0){
          recChar = recChar1;
          sendFlag = true;
      }
      else if (mode == 1){
        tft.setRotation(1);
        tft.fillRect(0, 0, 80, 50, ILI9341_BLUE);
        tft.drawRect(0, 0, 80, 50, ILI9341_WHITE);
        tft.setCursor(30, 10);
        tft.setTextSize(5);
        tft.print(recChar1);
        tft.fillRect(0, 50, 80, 50, ILI9341_BLUE);
        tft.drawRect(0, 50, 80, 50, ILI9341_WHITE);
        tft.setCursor(30, 60);
        tft.setTextSize(5);
        tft.print(recChar2);
        tft.fillRect(0, 100, 80, 50, ILI9341_BLUE);
        tft.drawRect(0, 100, 80, 50, ILI9341_WHITE);
        tft.setCursor(30, 110);
        tft.setTextSize(5);
        tft.print(recChar3);
        tft.setRotation(0);
        bool selected = false;
        now = millis();
        old_time = now;
        p.x = 240;
        p.y = 320;
        while(!selected){
          now = millis();
          p = ctp.getPoint();
          p.x = map(p.x, 0, 240, 240, 0);
          p.y = map(p.y, 0, 320, 320, 0);
          if (now - old_time > 50){
            old_time = now;
            if (p.y < 80 && p.x > 190){
              recChar = recChar1;
              sendFlag = true;
              selected = true;
            }
            else if ((p.y < 80) && (p.x > 140)){
              recChar = recChar2;
              sendFlag = true;
              selected = true;
            }
            else if (p.y < 80 && (p.x > 90)){
              recChar = recChar3;
              sendFlag = true;
              selected = true;
            }
            else if (p.y < 80 && (p.x > 45)){
            }                           
            else if (p.y < 80 && (p.x > 0)){
              selected = true;
            }             
          }            
        }
      }
      for(int i = 1; i<=240; i++){
        for (int j = 1; j<=240; j++){
          if (oriImage[240 - i][j] == 1){
            oriImage[240-i][j] = 0;
            tft.drawPixel(i, j+80, ILI9341_BLACK);
          }
        }
      }
      for(int i = 0; i<32; i++){
        for(int j = 0; j<32; j++){
          downscaledImage[i][j] = 0;
        }
      }
     }
     
  }
  else{
  if (p.x != 0){

    // flip it around to match the screen.
    p.x = map(p.x, 0, 240, 240, 0);
    p.y = map(p.y, 0, 320, 320, 0);
    
  if (p.y < 80){
      now = millis();
      if ((p.x <45) && (now - old_time > 50)){
        old_time = now;
        tft.setRotation(1);
        tft.drawRect(0, 195, 80, 45, ILI9341_WHITE);
        wait_us(1000);
        tft.drawRect(0, 195, 80, 45, ILI9341_RED);
        tft.setRotation(0);
        recChar = 8;
        sendFlag = true;
      }
      else if ((p.x > 45 && p.x < 90) && (now - old_time > 50)){
        old_time = now;
        tft.setRotation(1);
        tft.setCursor(30, 165); tft.setTextSize(3);
        if (mode == 1){
          tft.fillRect(0, 150, 80, 45, ILI9341_GREEN);
          tft.print("F");
          mode = 0;
        }
        else if (mode == 0){
          tft.fillRect(0, 150, 80, 45, ILI9341_YELLOW);
          tft.print("S");
          mode = 1;
        }
        tft.setRotation(0);
      }
  }
    else{
      now = millis();
      if ((now - old_time < 30)){
          
          tft.startWrite();
          tft.writeAndRecordLine(x_old, y_old, p.x, p.y, ILI9341_RED, oriImage);
          tft.endWrite();
          writtenFlag = true;
          
          x_old = p.x;
          y_old = p.y;
        }
      else{
          x_old = p.x;
          y_old = p.y;
        }
      old_time = now;
      }
      
      wait_us(10);
    }
  }
    sem.release();
  }
}

void setup() {
 
  Serial.begin(115200);

  Serial.println(F("Cap Touch Paint!"));
  
  tft.begin();

  if (! ctp.begin(40)) {  // pass in 'sensitivity' coefficient
    Serial.println(F("Couldn't start FT6206 touchscreen controller"));
    while (1);
  }

  Serial.println(F("Capacitive touchscreen started"));
  
  tft.fillScreen(ILI9341_BLACK);
  
  // make the color selection boxes
  tft.fillRect(0, 0, BOXSIZE*6, 80, ILI9341_BLUE);
  tft.setRotation(1);
  tft.drawRect(0, 0, 80, 50, ILI9341_WHITE);
  tft.drawRect(0, 50, 80, 50, ILI9341_WHITE);
  tft.drawRect(0, 100, 80, 50, ILI9341_WHITE);
  tft.fillRect(0, 150, 80, 45, ILI9341_GREEN);
  tft.fillRect(0, 195, 80, 45, ILI9341_RED);
  tft.setTextColor(ILI9341_WHITE);  
  tft.setCursor(30, 165); tft.setTextSize(3);
  tft.println("F");
  tft.setCursor(12, 215); tft.setTextSize(1);
  tft.println("Backspace");
  tft.setRotation(0);

  Serial.println("Initialized Successful 1");
  
  t1.start(func1);
  Serial.println("Thread 1 initialized");
  bleKb.initialize();
  MbedBleHID_RunEventThread();

}

void loop(){

    // When disconnected, we animate the builtin LED to indicate the device state.
  if (bleKb.connected() == false) {
    animateLED(LED_BUILTIN, (bleKb.has_error()) ? 118 
                                                : 1185);

    return;
  }
  
  sem.acquire();

  auto *kb = bleKb.hid();

  if (sendFlag == true){
    kb->sendCharacter(recChar);
    sendFlag = false;
  }

    sem.release();

  wait_us(20);
  
}

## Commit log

2021-12-12 Upload testing result and source code
    [testing_fast_mode.xlsx, testing_slow_mode.xlsx]
2021-12-12 Update PCB
